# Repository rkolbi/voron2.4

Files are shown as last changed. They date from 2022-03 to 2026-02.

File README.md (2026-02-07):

##  :crystal_ball:A collection of Klipper related things.

Main files:

**[:zap:](DK-TAP-SENSORLESS-EBB36-CPAP-BEDFANS)My currently running configuration setup (Kalico, ChaoticLab Tap V2, EBB36 Can, Sensorless XY, CPAP Part Cooling, and Bedfans).**

**[:bulb:](gcode_folder_share.txt)How to network share your gcode folder.**

**[:bulb:](ADXL345-NANO.txt)Using an Arduino nano & ADXL345.**

**[:bulb:](PA_CAL-V1)Pressure Advance Macro - version 1.**

**[:bulb:](PA_CAL-V2)Pressure Advance Macro - version 2.**

**[:wrench:](printer.cfg)Full Monolithic printer.cfg.**

**[:wrench:](Euclid)Portable Euclid probe macros.**

<br><br>
:hear_no_evil::see_no_evil::speak_no_evil: If you have any suggestions for a change, addition, or correction - please feel free to submit it [here](https://github.com/rkolbi/voron2.4/discussions/new?category=ideas).

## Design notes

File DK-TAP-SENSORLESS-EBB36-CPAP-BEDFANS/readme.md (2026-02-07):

# Voron 2.4 Configuration
## with Voron TAP, Sensorless X&Y Homing, EBB36 CAN Toolhead, and CPAP Part Cooling

---

This Kalico (DangerKlipper) configuration is optimized for the Voron 2.4 3D printer, providing comprehensive automation and advanced features for exceptional print quality and user experience.

---

## Configuration Overview

### Modular File Management

This configuration uses an intelligent directory-based system for organizing configuration files:

- **ACTIVE Directory**: All `.cfg` files in this directory are automatically loaded by Klipper
- **INACTIVE Directory**: Files stored here are ignored, allowing easy testing and organization
- **Easy Management**: Edit files via Samba network shares or SSH as if they were on your desktop

**To disable a configuration file:**
- Rename the extension (e.g., `feature.cfg` → `feature.cfgno`), OR
- Move it to the INACTIVE directory

### Central Configuration (printer.cfg)

The root `printer.cfg` file serves as the central hub:
- Automatically loads all `.cfg` files from the ACTIVE directory
- Contains global variables used throughout the macro system
- Stores auto-generated parameters (input shaper, saved mesh, etc.) at the bottom

### Printer-Specific Settings

Hardware-specific configurations are organized in dedicated files like `CONFIG-V24-350-TAP-SENSORLESS.cfg`. The modular approach ensures portability and makes updates straightforward.

---

## Key Features

### Dynamic Motor Current System

This configuration implements an intelligent safety feature:
- **Low currents** during homing and maintenance (prevents damage from collisions)
- **High currents** automatically applied during printing (full performance)
- **Collision protection** reduces risk of bent rods or damaged components

### Advanced Macro Suite

- **Adaptive Bed Mesh**: Meshes only the print area for faster, smarter leveling
- **Heat Soak Management**: Configurable pre-print chamber stabilization
- **Automated Homing & Leveling**: QGL and mesh calibration with thermal protection
- **Bed Fan Control**: Automatic chamber temperature management
- **Filament Handling**: Load/unload macros with customizable settings
- **LED Effects Integration**: Dynamic status indication (requires klipper-led_effect plugin)
- **Calibration Helpers**: PA_CAL, PID tuning, ADXL measurements

---

## Configuration Highlights

### PRINT_START Macro

The PRINT_START macro automates the entire print preparation workflow:

**Key Features:**
1. **Heat Soak Cycle**: Stabilizes chamber temperature before printing (configurable duration)
2. **Intelligent Homing**: Performs QGL and homing at optimal temperatures
3. **Adaptive Mesh**: Automatically meshes only the required print area
4. **Thermal Protection**: Ensures safe probing temperatures for Voron TAP
5. **Purge Line**: Two-stage purge for flow verification and nozzle priming
6. **Flexible Control**: Heat soak can be terminated early via RESUME or WAIT_QUIT

**Slicer Integration:**

For **OrcaSlicer/PrusaSlicer**, use this Start G-code:

```gcode
PRINT_START BED_TEMP=[first_layer_bed_temperature] EXTRUDER_TEMP=[first_layer_temperature] EXTRUDER_TEMP2=[temperature] CHAMBER_TEMP=[chamber_temperature] PA=0.040 ST=0.020 SIZE={first_layer_print_min[0]}_{first_layer_print_min[1]}_{first_layer_print_max[0]}_{first_layer_print_max[1]}
```

For **SuperSlicer**, use:

```gcode
PRINT_START BED_TEMP=[first_layer_bed_temperature] EXTRUDER_TEMP=[first_layer_temperature] EXTRUDER_TEMP2=[temperature] ENCLOSURE_TEMP=[chamber_temperature] PA=0.040 ST=0.020 SIZE={first_layer_print_min[0]}_{first_layer_print_min[1]}_{first_layer_print_max[0]}_{first_layer_print_max[1]}
```

**Optional Parameters:**

The following parameters can be specified in your slicer start code, or defaults from `printer.cfg` will be used:

- `PA=0.040` - Pressure advance value
- `ST=0.020` - Pressure advance smooth time
- `SOAK=15` - Heat soak duration in minutes (reduce for PLA/PETG, increase for ABS/ASA)
- `CHAMBER_TEMP=45` - Target chamber temperature for bed fan control

---

### LC_PAUSE (Layer Change Pause) Macro

Provides intelligent layer-based pausing functionality:

**Features:**
- Pause at next layer change (no parameter needed)
- Pause at specific layer (pass layer number as parameter)
- Toggle behavior (calling LC_PAUSE again cancels the pause)
- Seamless slicer integration

**Slicer Integration:**

Add to **After Layer Change G-code** in your slicer:

```gcode
_LAYER_CHANGE LAYER={layer_num}
```

**Usage Examples:**
```gcode
LC_PAUSE           # Pause on next layer
LC_PAUSE LAYER=50  # Pause when layer 50 starts
```

---

### PRINT_END Macro

Handles post-print cleanup and safety:

**Actions Performed:**
1. **Print Clearance**: Raises toolhead 10mm to prevent nozzle contact
2. **Cooling Activation**: Part cooling fan to 100% for rapid cooldown
3. **Smart Parking**: Positions toolhead for easy inspection and access
4. **Fan Clearance**: Moves to Y20 for unobstructed airflow
5. **Motor Current Reset**: Returns to low currents for safety

**Slicer Integration:**

Add to **End G-code**:

```gcode
PRINT_END
```

---

### PA_CAL (Pressure Advance Calibration) Macro

Simplified pressure advance tuning:

**Features:**
- Line-based PA test pattern
- Automatic value incrementation
- Customizable test parameters
- Visual validation of results

**Usage:**

```gcode
PA_CAL                                    # Use defaults from printer.cfg
PA_CAL BED=110 EXTRUDER_TEMP=245          # Specify temperatures
PA_CAL PA_START=0.020 PA_STEP=0.005       # Custom PA range
```

The macro prints test lines with incrementing PA values. Inspect the lines to find where corners look best (no bulging or gaps), then update your `printer.cfg` and slicer settings.

---

## Hardware Specifications

### Current Configuration

- **Printer**: Voron 2.4 (350mm build volume)
- **Firmware**: Kalico (DangerKlipper fork)
- **Mainboard**: BTT Octopus or similar (TMC2209 drivers)
- **Toolhead**: BTT EBB36 CAN board via U2C bridge
- **Probe**: Voron TAP with thermal protection
- **Homing**: Sensorless X/Y via TMC2209 StallGuard
- **Part Cooling**: CPAP blower with WS7040 driver
- **Extruder**: BMG-style (Bondtech LGX or similar)

### Performance Settings

- **Max Velocity**: 300 mm/s
- **Max Acceleration**: 4000 mm/s²
- **Print Acceleration**: 4000 mm/s² (via globalvariables)
- **Square Corner Velocity**: 6.0 mm/s
- **Pressure Advance**: 0.040 (tune for your filament)
- **Input Shaper**: Auto-calibrated (stored in SAVE_CONFIG)

---

## Network File Sharing Setup (Optional)

Enable easy file access from your desktop via Samba network shares.

### Installation

SSH into your Raspberry Pi and run:

```bash
sudo apt-get install samba winbind -y
```

### Configuration

Edit the Samba configuration file:

```bash
sudo nano /etc/samba/smb.conf
```

Add the following to the end of the file:

```ini
[Print_Files]
   comment = Voron G-Code Files
   path = /home/pi/printer_data/gcodes
   browseable = Yes
   writeable = Yes
   only guest = no
   create mask = 0777
   directory mask = 0777
   public = yes
   read only = no
   force user = root
   force group = root

[Klipper_Configs]
   comment = Voron Klipper Configuration
   path = /home/pi/printer_data/config
   browseable = Yes
   writeable = Yes
   only guest = no
   create mask = 0777
   directory mask = 0777
   public = yes
   read only = no
   force user = root
   force group = root

[Klipper_Storage]
   comment = Voron Storage
   path = /home/pi/Storage
   browseable = Yes
   writeable = Yes
   only guest = no
   create mask = 0777
   directory mask = 0777
   public = yes
   read only = no
   force user = root
   force group = root
```

### Apply Changes

Reboot your Raspberry Pi:

```bash
sudo reboot
```

### Windows Troubleshooting

If Windows shows a red X on mapped network shares, run CMD as administrator and execute:

```cmd
net stop workstation /y
net start workstation
```

### Accessing Shares

From Windows File Explorer or macOS Finder, navigate to:
```
\\your-printer-ip\Print_Files
\\your-printer-ip\Klipper_Configs
\\your-printer-ip\Klipper_Storage
```

---

## Tuning & Calibration

### Recommended Calibration Sequence

1. **PID Tuning** (Bed & Hotend)
   ```gcode
   PID_BED_CAL
   PID_NZL_CAL
   ```

2. **Input Shaper** (after toolhead assembly)
   ```gcode
   SHAPER_CALIBRATE
   # Or use: HEATSOAKED_ADXL for thermally stable measurements
   ```

3. **Pressure Advance** (for each filament type)
   ```gcode
   PA_CAL BED=110 EXTRUDER_TEMP=245 PA_START=0.020 PA_STEP=0.005
   ```

4. **First Layer & Z Offset** (with Voron TAP)
   - Heat bed to printing temperature
   - Run `QUAD_GANTRY_LEVEL`
   - Use paper test or first layer calibration print
   - Adjust via `SET_GCODE_OFFSET Z_ADJUST=±0.xxx` then `Z_OFFSET_APPLY_PROBE`

### Material-Specific Heat Soak Times

Adjust `SOAK` parameter in your slicer for different materials:

- **PLA**: `SOAK=0` or `SOAK=5` (minimal heat soak needed)
- **PETG**: `SOAK=5` to `SOAK=10`
- **ABS/ASA**: `SOAK=15` to `SOAK=20` (default, recommended)
- **Nylon/PC**: `SOAK=20` to `SOAK=30`

---

## Additional Resources

### Documentation & References

- **This Configuration**: [GitHub Repository](https://github.com/rkolbi/voron2.4/tree/main/MY_V24-350)
- **Adaptive Mesh**: [Frix-x's Klippain](https://github.com/Frix-x/klippain/blob/main/macros/calibration/adaptive_bed_mesh.cfg)
- **LED Effects**: [klipper-led_effect Plugin](https://github.com/julianschill/klipper-led_effect)
- **Sensorless Homing**: [Clee's Guide](https://docs.vorondesign.com/community/howto/clee/sensorless_xy_homing.html)

### Klipper Resources

- **Klipper Documentation**: [Main Docs](https://www.klipper3d.org/Overview.html)
- **Configuration Reference**: [Config Reference](https://www.klipper3d.org/Config_Reference.html)
- **G-Code Commands**: [G-Code Reference](https://www.klipper3d.org/G-Codes.html)
- **TMC Drivers**: [TMC Documentation](https://www.klipper3d.org/TMC_Drivers.html)
- **Klipper GitHub**: [Main Repository](https://github.com/Klipper3d)
- **Klipper Reddit**: [r/klippers](https://www.reddit.com/r/klippers/)

### Voron Resources

- **Voron Documentation**: [Build Guides](https://docs.vorondesign.com/build/)
- **Voron GitHub**: [VoronDesign](https://github.com/VoronDesign)
- **Voron Reddit**: [r/VORONDesign](https://www.reddit.com/r/VORONDesign/)

### Hardware Links

- **Euclid Probe**: [Documentation](https://euclidprobe.github.io/)
- **Bondtech LGX Extruder**: [Product Page](https://www.bondtech.se/product/lgx-large-gears-extruder/)
- **Bondtech CHT Nozzle**: [Product Page](https://www.bondtech.se/product/bondtech-cht-coated-brass-nozzle/)
- **MandalaRoseWorks Kinematic Mounts**: [Product Page](https://mandalaroseworks.com/products/matched-height-kinematic-kit)
- **MandalaRoseWorks Ultraflat Bed**: [Product Page](https://mandalaroseworks.com/products/voron-350-ultraflat-bed)

### General 3D Printing

- **RepRap G-code Wiki**: [G-code Reference](https://reprap.org/wiki/G-code)
- **Jinja2 Templates**: [Syntax Guide](https://jinja.palletsprojects.com/en/2.10.x/templates/)

---

## Configuration Philosophy

This configuration emphasizes:

1. **Safety First**: Dynamic current control, thermal protection, collision prevention
2. **Automation**: Minimize manual steps, maximize reliability
3. **Flexibility**: Easy to modify, well-documented, modular structure
4. **Performance**: Optimized for speed without sacrificing quality
5. **User Experience**: Clear feedback, intuitive controls, comprehensive macros

---

## Support & Contributions

For issues, improvements, or questions about this configuration:
- Review the documentation above
- Check Klipper and Voron documentation
- Consult the community resources linked above
- Submit issues or pull requests to the GitHub repository

---

**Last Updated**: February 7, 2026  
**Firmware**: Kalico v2026.02.00-0-gc70d21ab

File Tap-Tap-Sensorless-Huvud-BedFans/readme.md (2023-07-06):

****Voron 2.4 Configuration with Tap, Sensorless X&Y Homing, Bed Fans, and Huvud w/U2C****  
------

This Klipper configuration is tailored for the Voron 2.4 3D printer with Tap, offering a range of features to optimize your printing experience. Here's an overview of the key enhancements:

**Macro File Management:**

The configuration simplifies file management by automatically pulling all ".cfg" files from the ACTIVE directory while excluding any files in the INACTIVE directory. You can conveniently move and edit files using Samba or other networking file-share services as if they were on your desktop. To exclude a file from Klipper, rename its extension within the ACTIVE directory (e.g., "do_stuff.cfg" to "do_stuff.cfgno"), or move it to the INACTIVE directory. Please refer to the instructions below if you require assistance setting up Samba network sharing.

**printer.cfg:**

The root directory includes a "printer.cfg" file that loads all ".cfg" files from the ACTIVE directory. It also serves as a centralized location for modifying global variables used by the included macros. Additionally, any saved parameters generated by Klipper are stored at the bottom of the "printer.cfg" file for easy access and management.

**Printer-Specific Configurations:**

To accommodate printer-specific settings, you can create a dedicated file such as "CONFIG-VORON24_350.cfg" (feel free to choose a different name if preferred). This configuration file is specific to your Voron 2.4 printer, allowing you to organize the contents further. Remember that "printer.cfg" automatically loads all ".cfg" files from the ACTIVE directory, irrespective of their names. Therefore, it's crucial to use meaningful and portable filenames to ensure ease of use and future compatibility.<br>  
<br>

### Configuration Bundle Highlights
------

#### **PRINT_START macro**:

1. Automation: The PRINT_START macro automates multiple steps before starting a print, such as heat soaking, toolhead warming, gantry homing, and leveling. 
2. Heat-soak cycle: The macro includes a heat-soak cycle that allows the printer to stabilize its temperature before starting the actual print. This cycle is crucial for ensuring that the printer operates at the desired temperature, which is essential for successful printing and proper filament adhesion.
3. Gantry homing and leveling: As the heat-soak cycle begins, the PRINT_START macro also performs gantry homing and leveling. This step prevents any undue stress on the gantry as chamber temperatures rise, ensuring that the gantry remains properly aligned.
4. Flexibility: The heat-soak cycle can be terminated early by selecting RESUME or executing the WAIT_QUIT macro. This flexibility allows users to abort the heat-soak cycle if needed, for example, when encountering unexpected issues or when wanting to start the print sooner.
5. Adaptive Mesh: The PRINT_START macro incorporates the use of Adaptive Mesh, which improves bed leveling and compensates for any imperfections in the printing surface within the print area of the object itself. This step enhances the first-layer adhesion and overall print quality by adjusting the printing parameters based on the actual surface conditions.
6. Purge line and pressure advance proof: The macro includes a purge line and a simple line-based pressure advance proof. The purge line allows users to verify key aspects of the printer's performance, such as filament flow and pressure advance, ensuring that the printer is functioning correctly before starting the actual print.

Overall, the advantages of the PRINT_START macro lie in its automation of critical steps, gantry leveling, and temperature stabilization, flexibility in terminating the heat-soak cycle, the inclusion of Adaptive Mesh for improved bed leveling, and simplified verification of key printer parameters. These advantages contribute to a streamlined and efficient workflow, enhancing print quality and user experience.

The **Start G-code** block in SuperSlicer should contain the following line:

```
PRINT_START BED_TEMP=[first_layer_bed_temperature] EXTRUDER_TEMP=[first_layer_temperature] EXTRUDER_TEMP2=[temperature] CHAMBER_TARGET=[chamber_temperature] PA=0.045 ST=0.21 SIZE={first_layer_print_min[0]}{first_layer_print_min[1]}{first_layer_print_max[0]}_{first_layer_print_max[1]}
```

The following optional parameters can be specified, or the values set in "printer.cfg" will be used:

- **EXTRUDER_WARM**: The nozzle temperature to be used when performing the heated homing and leveling, just before printing.
- **PA**: Pressure advance, e.g., `PA=0.045`
- **ST**: Pressure advance smooth-time, e.g., `ST=0.21`
- **SOAK**: Minutes to heat-soak before final G32, meshing, and printing, e.g., `SOAK=15`
- **CHAMBER_TEMP**: The desired temperature for the chamber, e.g., `CHAMBER_TEMP=50`
- **fpline**: E value for first 120mm prime line, implemented as (fpline * NZLD), e.g., `fpline=37.5`
- **spline**: E value for second 120mm prime line, implemented as (spline * NZLD), e.g., `spline=75.0`
<br>

#### **Bed-Fan macro set:**

The Bed-Fan Macro Set offers enhanced functionality for the control of bed fans according to specific temperature conditions, providing effective control of the chamber temperature during print. 
1. Adaptive Fan Speed Control: With the macro activated, the bed fan speed seamlessly adapts to the current temperature conditions, using variable speeds to control chamber temperature while reducing temperature fluctuations witnessed on the bed. If the heater bed target temperature is below the bed-fan trigger threshold, the bed fans will be disabled.
2. Chamber Temperature Monitoring: The macro actively monitors the temperature within the chamber, ensuring that the printing environment maintains an optimal temperature range. This feature helps to enhance print quality and prevent potential issues caused by temperature fluctuations.
3. When using the gcode command `M190`, which optionally sets a new target temperature for the heated bed and waits for the target temperature to be reached before proceeding, the chamber heat-up cycle is similar in that it waits for the set temperature but will proceed regardless after 15 minutes. 

<br>  

#### **LC_PAUSE (Layer Change) macro:**

1. Convenience: The LC_PAUSE macro provides a simple and user-friendly mechanism for controlling the "Pause on the next layer" functionality. This functionality allows users to pause the printing process at a specific layer and perform certain actions or make adjustments as needed.
2. Flexibility: The macro allows flexibility in how the pause functionality is applied. Users can either pause at the next layer change by not specifying a specific layer value or trigger a pause only when a specific layer number is passed as a parameter to the macro. This flexibility caters to different use cases and allows users to customize the behavior according to their requirements.
3. Dynamic behavior: The LC_PAUSE macro considers the current state of the "Pause on the next layer" flag. If LC_PAUSE has already been set, executing the macro will toggle it off, effectively canceling the pause. This dynamic behavior ensures that users have control over the pause functionality and can easily modify it during runtime without complications.
4. Integration with slicer functionality: The macro integrates with the slicer's layer change mechanism by checking the slicer's passed layer value and comparing it with the user's specified layer. This integration enhances the compatibility and interoperability between the macro and the slicer, resulting in a more seamless workflow when managing layer-based pausing in a slicer environment.

Overall, the advantages of the LC_PAUSE macro lie in its convenience, flexibility, dynamic behavior, and integration with slicer functionality, making it a helpful tool for managing layer-based pausing in a slicer environment.

The **After Layer Change G-code** block in SuperSlicer should contain the following to enable the Pause on the next Layer Change (LC_PAUSE) command:

```
_LAYER_CHANGE LAYER={layer_num}
```

<br>  

#### **PRINT_END macro:**

1. Print clearance: When completed, the PRINT_END macro raises the toolhead by 10mm to prevent the nozzle from scarring or damaging the finished print. This step helps maintain the quality and appearance of the printed object, preventing accidental contact between the nozzle and the print.
2. Cooling activation: The macro activates the part cooling fan to 100% after the print is finished. This helps cool down the hotend and reduces the chances of stringing or unwanted filament deposits that can occur when the nozzle remains hot after the print has ended.
3. Toolhead parking: The macro parks the toolhead towards the printer's top, in the front-right position. This parking position is strategically chosen to provide optimal accessibility for visual inspection of the toolhead and nozzle, making it easier to identify and clean any debris or filament residue that may have accumulated during the print.
4. Fan clearance: The macro moves the toolhead back to Y20, allowing the fans to pull air without being obstructed by the printer's doors. This step ensures proper airflow and cooling efficiency by preventing obstructions that may impede the fans' ability to circulate air effectively and cool down the printer components.
5. Safety and maintenance: The actions performed by the PRINT_END macro contribute to the safety and maintenance aspects of 3D printing. Raising the toolhead reduces the risk of accidental damage or interference with the printed object when removing it from the build plate. Activating cooling helps prevent overheating of the printer components, which can lead to premature wear or malfunction. Parking the toolhead in a suitable position allows for easy inspection and cleaning, enhancing the longevity and reliability of the printer and preparing it for the next print job.

Overall, the advantages of the PRINT_END macro lie in its print clearance, cooling activation, toolhead parking at an accessible position, and fan clearance for proper airflow. These advantages ensure a smooth and efficient end to the print job while promoting print quality, user convenience, and printer longevity.

The **End G-code** block in SuperSlicer should contain the following line:

```
PRINT_END
```

<br>  

#### **PA_CAL (Pressure Advance) macro:**

1. Simplified Pressure Advance Testing: The PA_CAL macro enables users to perform a quick, straightforward, line-based pressure advance test. It prints a line with the current pressure advance (PA) setting, moves 30mm, and then prints 20 line segments, each 5mm apart, incrementing the PA value for each line. This simplified testing process allows users to quickly assess and fine-tune their pressure advance settings more efficiently, leading to improved print quality.
2. Customizable Parameters: The macro supports optional parameters for adjusting the test conditions. Users can specify the bed temperature (BED), extruder temperature (EXTRUDER_TEMP), initial PA value (PA_START), PA increment (PA_STEP), and nozzle diameter (NZL). This customization allows users to tailor the test conditions to their specific requirements and experiment with different settings, facilitating optimization.
3. Default Values: If no parameters are specified, the macro provides default values for the optional parameters. These default values are retrieved from the printer's configuration file or other global variables, ensuring users can perform the test without specifying all the parameters. This feature makes the macro more user-friendly and accessible.
4. Test Validation: The macro provides a mechanism to validate the test results by comparing the estimated PA threshold value with the user-specified PA threshold. This validation step helps users accurately identify the optimal PA setting and ensure reliable and consistent results during the pressure advance tuning process.

Overall, the advantages of the PA_CAL macro lie in its simplified pressure advance testing, customizable parameters, default values, and test validation. These features facilitate the optimization of pressure advance settings, allowing users to achieve better print quality and performance in their 3D prints.

<br>  
<br>

:bulb: For more information on the adaptive mesh, refer to Frix-x's github [here](https://github.com/Frix-x/klippain/blob/main/macros/calibration/adaptive_bed_mesh.cfg).

:bulb: These configs utilize Julianschill's Klipper LED Effects plugin, which can be found in [this GitHub repository](https://github.com/julianschill/klipper-led_effect).

:bulb: Bed-fan macro set is based on AndrewEllis93's work, which can be found in [this GitHub repository](https://github.com/VoronDesign/VoronUsers/tree/master/printer_mods/Ellis/Bed_Fans).

:bulb: Sensorless homing is based on Clee's work. You can find more information on sensorless XY homing for Voron printers [here](https://docs.vorondesign.com/community/howto/clee/sensorless_xy_homing.html), and Klipper documentation on TMC Drivers [here](https://www.klipper3d.org/TMC_Drivers.html#sensorless-homing).

<br>  
<br>  

### **HUVUD Setup**
------

TAP probe (optical) with Huvud toolhead controller wiring diagram follows. Detailed information on CAN [here](CAN-Application.pdf).

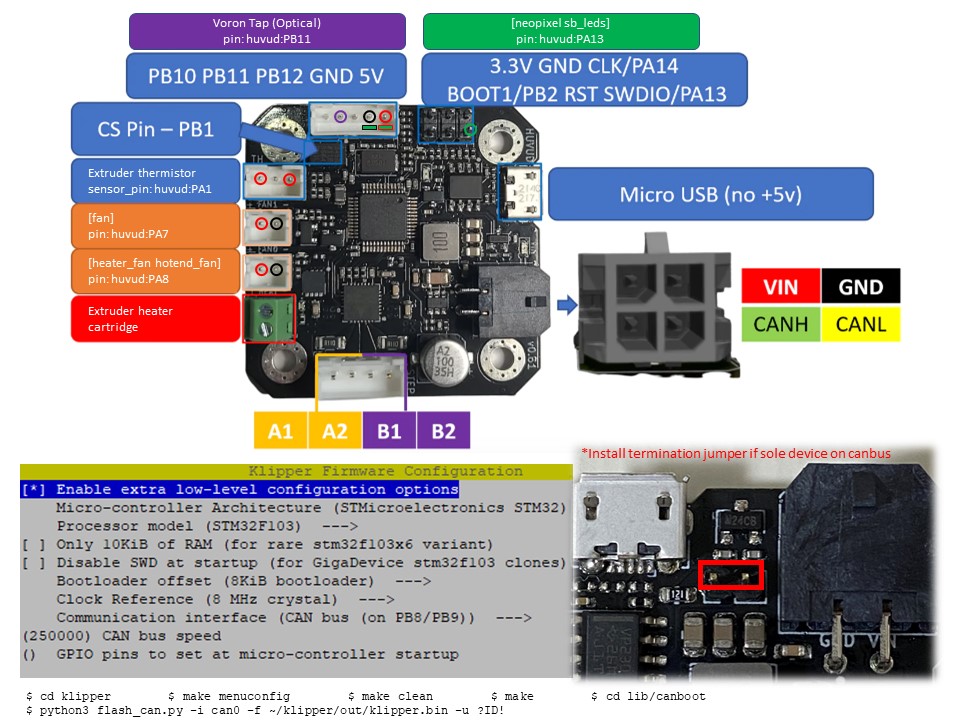
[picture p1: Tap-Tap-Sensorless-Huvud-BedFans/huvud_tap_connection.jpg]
HUVUD_TAP_Wiring

          
<br>

### **SAMBA Setup - GCODE File Network Share Setup**
------

To set up a network file share, making your gcode and Klipper config files available to all your network-attached devices - either Windows or Mac file explorers, perform the following once ssh'd into your Klipper rPi. Note that this samba configuration is 'open' and therefore accessible to any device attached to the same LAN, just as the Mainsail HTTP interface is. While it is possible to further restrict access to these Samba file shares, I feel it is a moot point given the nature of the rest of the software suite, so I will not cover that here. If this is worrisome to you, please research alternate configurations. 

 -Install file serving smb service:  
$`sudo apt-get install samba winbind -y`  

 -Configure file share.  Add the following to the end of the smb.conf file:  
$`sudo nano /etc/samba/smb.conf`  
	
```
[Print_Files]
   comment = Voron_gCode_files
   path = /home/pi/printer_data/gcodes
   browseable = Yes
   writeable = Yes
   valid users = @pi

[Klipper_Configs]
   comment = Voron_Klipper
   path = /home/pi/printer_data/config
   browseable = Yes
   writeable = Yes
   valid users = @pi

[Klipper_Storage]
   comment = Voron_Storage
   path = /home/pi/Storage
   browseable = Yes
   writeable = Yes
   valid users = @pi
```

Then create a Samba user for the pi user by running the following command.
```
sudo smbpasswd -a pi
```

Lastly, restart the Samba service to apply the changes.
```
sudo service smbd restart
```

In the event that Windows shows a red-x through the mapped share, I have found the following helpful in restoring mapped network shares:  
- Run `CMD` as administrator  
- `net stop workstation /y`  
- `net start workstation`  

<br>  

### **Links**
------

My Github (This file)                     https://github.com/rkolbi/voron2.4/tree/main/Tap-Tap-Sensorless-Huvud-BedFans  
RepRap G-code Wiki                        https://reprap.org/wiki/G-code  
Klipper Documentation (Main):             https://www.klipper3d.org/Overview.html    
Klipper Configuration Reference:          https://www.klipper3d.org/Config_Reference.html    
Klipper G-Code & Additional Commands:     https://www.klipper3d.org/G-Codes.html    
Klipper Github:                           https://github.com/Klipper3d    
Klipper Reddit:                           https://www.reddit.com/r/klippers/    
Jinja2 Syntax & Semantics:                https://jinja.palletsprojects.com/en/2.10.x/templates/    
Voron Documentation:                      https://docs.vorondesign.com/build/    
Voron Github:                             https://github.com/VoronDesign    
Voron Reddit:                             https://www.reddit.com/r/VORONDesign/    
Euclid Probe:                             https://euclidprobe.github.io/    
Bondtech LGX:                             https://www.bondtech.se/product/lgx-large-gears-extruder/    
Bontech CHT Nozzle:                       https://www.bondtech.se/product/bondtech-cht-coated-brass-nozzle/    
MandalaRoseWorks Kinematic Mounts:        https://mandalaroseworks.com/products/matched-height-kinematic-kit   
MandalaRoseWorks Ultraflat Mag Bed:       https://mandalaroseworks.com/products/voron-350-ultraflat-bed

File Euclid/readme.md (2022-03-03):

********* Instructions *********
1. Create a new Folder named "Euclid" in your /klipper_config folder
2. Copy the voron_euclid.cfg and the printer_size_xxx.cfg to the new created folder
3. Adapt the marked things inside the files to your Printer
4. You have to adapt parameters inside both files

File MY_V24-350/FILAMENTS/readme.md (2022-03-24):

This is where all your filament specific overrides go.

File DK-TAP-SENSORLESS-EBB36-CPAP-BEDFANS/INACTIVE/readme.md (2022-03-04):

Place files here to avoid being loaded by klipper.

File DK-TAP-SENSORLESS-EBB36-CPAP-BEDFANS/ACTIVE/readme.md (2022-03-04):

This directory holds all .cfg files that will be loaded into Klipper.

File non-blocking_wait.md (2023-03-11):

Going from a blocking, uninterruptable, waiting routine to an interruptible, nonblocking, routine.  
Can see this in use at:
https://github.com/rkolbi/voron2.4/tree/main/Tap-Tap-Sensorless-Huvud
In the above example, WAIT_Quit has been integrated with the normal resume function to make it more stream lined for user control.

This first snippet is my heat-waiting routine, using for loops and G4 pauses. Minutes to wait are passed on macro call. While this works well and does it's job, there is no graceful way to exit this cycle.

```
[gcode_macro _HEAT_WAIT]
description: Heating cycle waiting routine
gcode:
    {% set MINUTES = params.MINUTES|default(10)|int %}
    {% set MSG = params.MSG|default("Warming...")|string %}
    {% for i in range(0, MINUTES) %}
        M117 {MSG} {MINUTES-i} minute remaining.
        {% for s in range(0, 60) %}
            SET_LED LED=nozzle INDEX=1 RED=.5 GREEN=0 BLUE=0
            SET_LED LED=nozzle INDEX=2 RED=0 GREEN=0 BLUE=.5
            G4 P500
            SET_LED LED=nozzle INDEX=1 RED=0 GREEN=0 BLUE=.5
            SET_LED LED=nozzle INDEX=2 RED=.5 GREEN=0 BLUE=0
            G4 P500
        {% endfor %}
    {% endfor %}
```

This second snippet bundle nearly duplicates the role of the above snipper, but the wait cycle can be exited by running the macro, "WAIT_Quit". Minutes to wait are passed on calling macro, "WAIT_Start". When the cycle has completed, or forced exited, the following process macro must be directly called within the 'FINAL ACTION' block in the "WAIT_Delayed" delayed macro.

```
[gcode_macro _WAIT_Variable]
variable_count: 300
variable_duration: 2
variable_waiting: False
# Total wait minutes is (duration * count) / 60 
gcode:

[delayed_gcode WAIT_Delayed]
gcode:
    {% set count = printer["gcode_macro _WAIT_Variable"].count|int %}
    {% set duration = printer["gcode_macro _WAIT_Variable"].duration|int %}
    M117 Pre-Print Heatsoaking... {((duration * count) / 60)|round(1)} minutes left.
    SET_GCODE_VARIABLE MACRO=_WAIT_Variable VARIABLE=count VALUE={count-1}
    {% if count > 0 %} _WAIT_Loop  {% endif %}
    {% if count == 0 %} 
        # FINAL ACION
        SET_GCODE_VARIABLE MACRO=_WAIT_Variable VARIABLE=waiting VALUE=False
        M118 Reached the end, do final action
        # FINAL ACION
    {% endif %}

[gcode_macro _WAIT_Loop]
gcode:
    {% set count = printer["gcode_macro _WAIT_Variable"].count|int %}
    {% set duration = printer["gcode_macro _WAIT_Variable"].duration|int %}
    UPDATE_DELAYED_GCODE ID=WAIT_Delayed DURATION={duration}
    {% if  count % 2 == 0 %}
        SET_LED LED=nozzle INDEX=1 RED=.5 GREEN=0 BLUE=0
        SET_LED LED=nozzle INDEX=2 RED=0 GREEN=0 BLUE=.5
      {% else %}
        SET_LED LED=nozzle INDEX=1 RED=0 GREEN=0 BLUE=.5
        SET_LED LED=nozzle INDEX=2 RED=.5 GREEN=0 BLUE=0
    {% endif %}

[gcode_macro WAIT_Start]
gcode:
    {% set MINUTES = params.MINUTES|default(15)|int %}
    {% set duration = printer["gcode_macro _WAIT_Variable"].duration|int %}
    {% set count = (MINUTES * 60) / duration %}
    SET_GCODE_VARIABLE MACRO=_WAIT_Variable VARIABLE=waiting VALUE=True
    SET_GCODE_VARIABLE MACRO=_WAIT_Variable VARIABLE=count VALUE={count}
    UPDATE_DELAYED_GCODE ID=WAIT_Delayed DURATION={duration}

[gcode_macro WAIT_Quit]
gcode:
    {% if printer["gcode_macro _WAIT_Variable"].waiting %}
        M118 STOPPING LOOP, SETTING COUNT TO 0
        SET_GCODE_VARIABLE MACRO=_WAIT_Variable VARIABLE=count VALUE=0
        UPDATE_DELAYED_GCODE ID=WAIT_Delayed DURATION=1
      {% else %}
        M118 Not in waiting state, nothing to do.
    {% endif %}
```

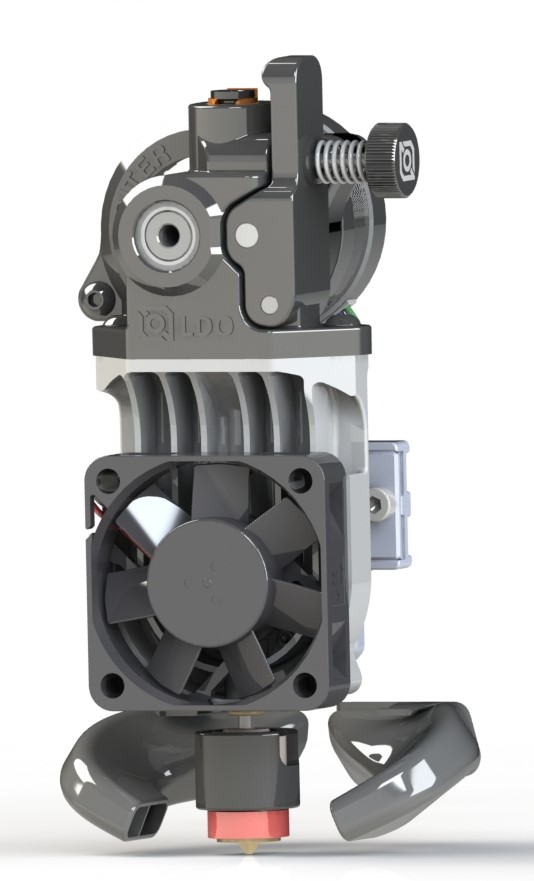
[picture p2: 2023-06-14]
CNC-Tap with Revo/buick.JPG

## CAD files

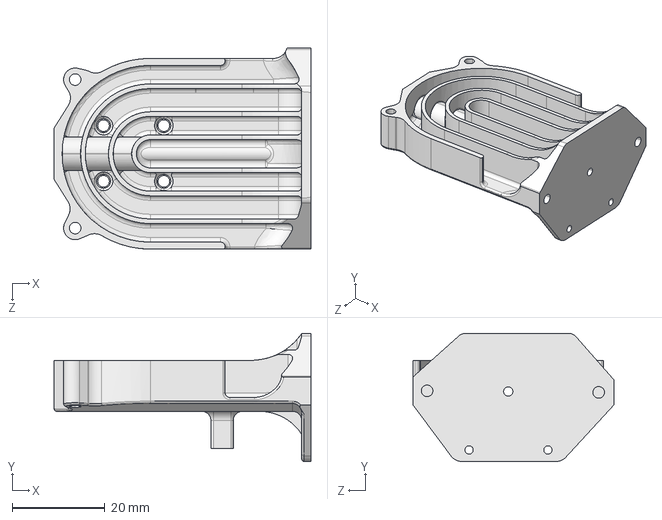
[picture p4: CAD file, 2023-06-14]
CNC-Tap with Revo/Revo-Heatsink.STEP
55.4 x 27.6 x 43.4 mm

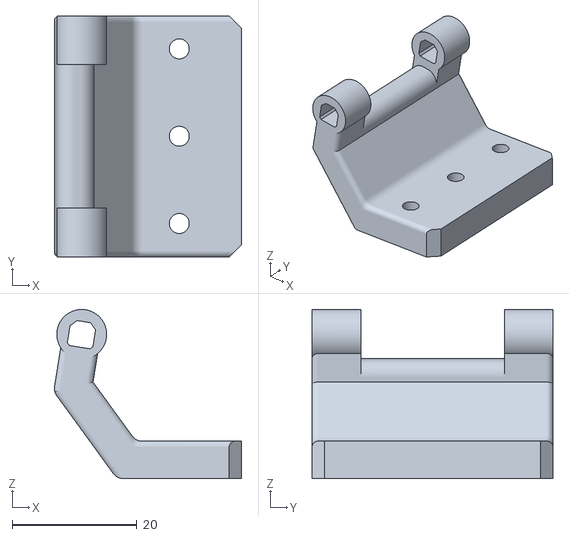
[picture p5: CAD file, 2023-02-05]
DK-TAP-SENSORLESS-EBB36-CPAP-BEDFANS/Other/STLs/c920-Top_Mount/C920_Top-Mount.stl
30.0 x 38.7 x 27.1

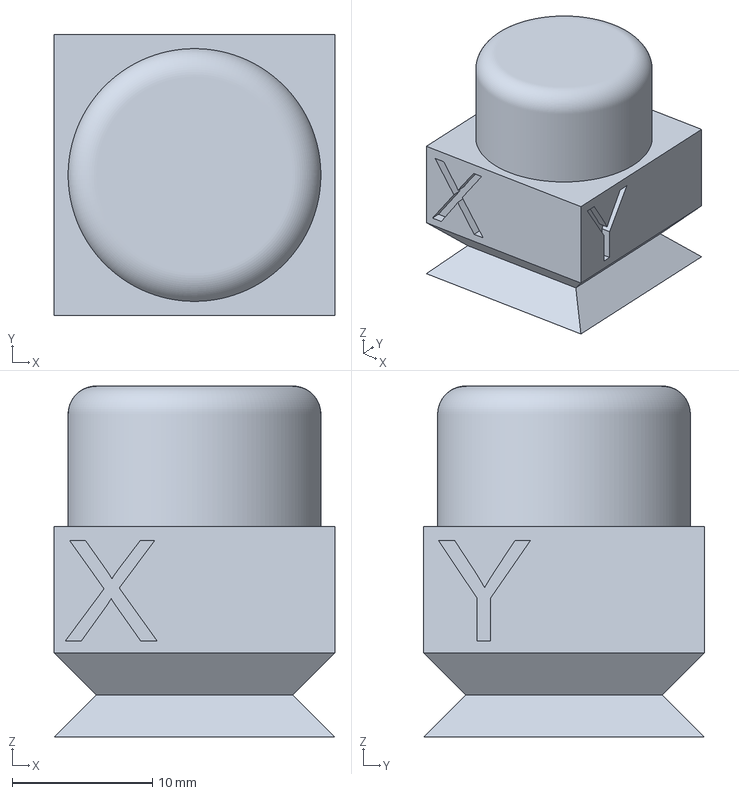
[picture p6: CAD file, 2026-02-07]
DK-TAP-SENSORLESS-EBB36-CPAP-BEDFANS/Other/STLs/Test-prints.3mf
20.0 x 20.0 x 25.0 mm

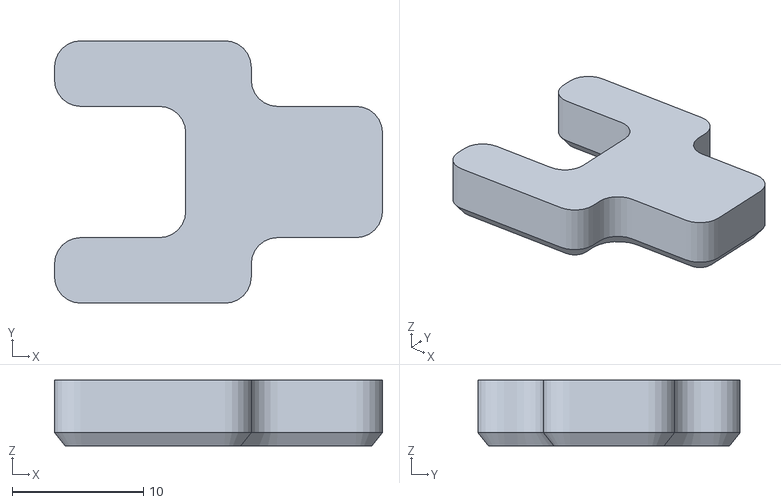
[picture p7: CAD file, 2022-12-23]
Other/Extrusion_Test.stl
25.0 x 20.0 x 5.00

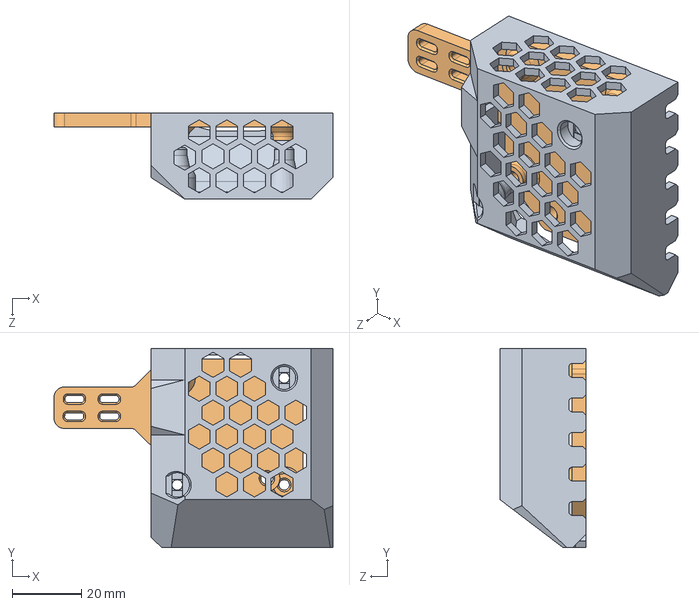
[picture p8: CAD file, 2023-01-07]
Tap-Tap-Sensorless-Huvud-BedFans/STLs/Huvud_mount_and_cover/StealthBurner_LGX_Huvud-Mount-and-Cover.STEP
80.8 x 57.8 x 25.0 mm
Cover-Huvud-to-LGX
Mount-Huvud-to-LGX

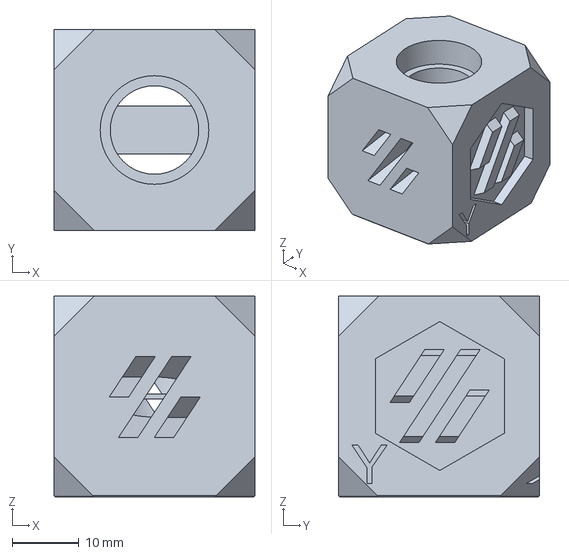
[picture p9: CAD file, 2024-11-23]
DK-TAP-SENSORLESS-EBB36-CPAP-BEDFANS/Other/STLs/Voron_Design_Cube_v7.3mf
30.0 x 30.0 x 30.0 mm

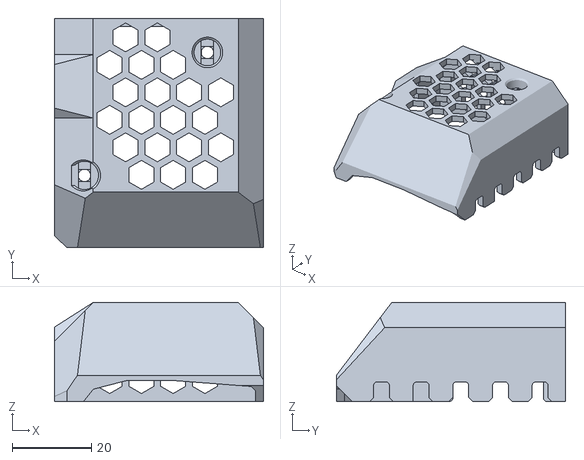
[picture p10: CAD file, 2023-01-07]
Tap-Tap-Sensorless-Huvud-BedFans/STLs/Huvud_mount_and_cover/Cover.STL
52.7 x 57.8 x 25.0

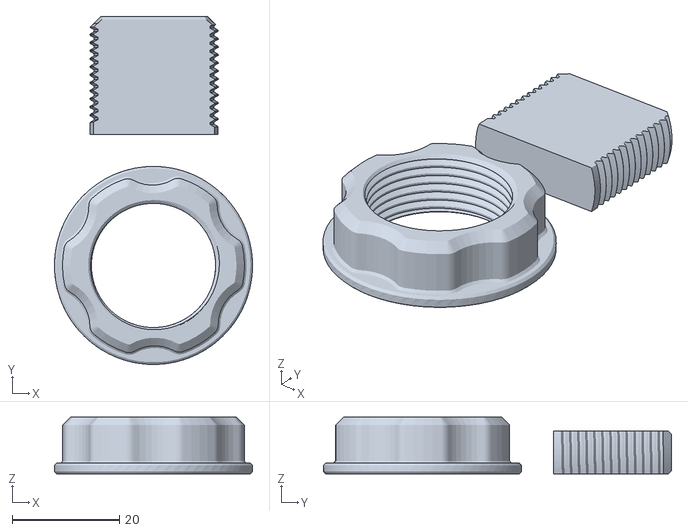
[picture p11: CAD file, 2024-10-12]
DK-TAP-SENSORLESS-EBB36-CPAP-BEDFANS/Other/STLs/Thread_Test_3_x1_Rev1.STL
37.0 x 65.0 x 10.6

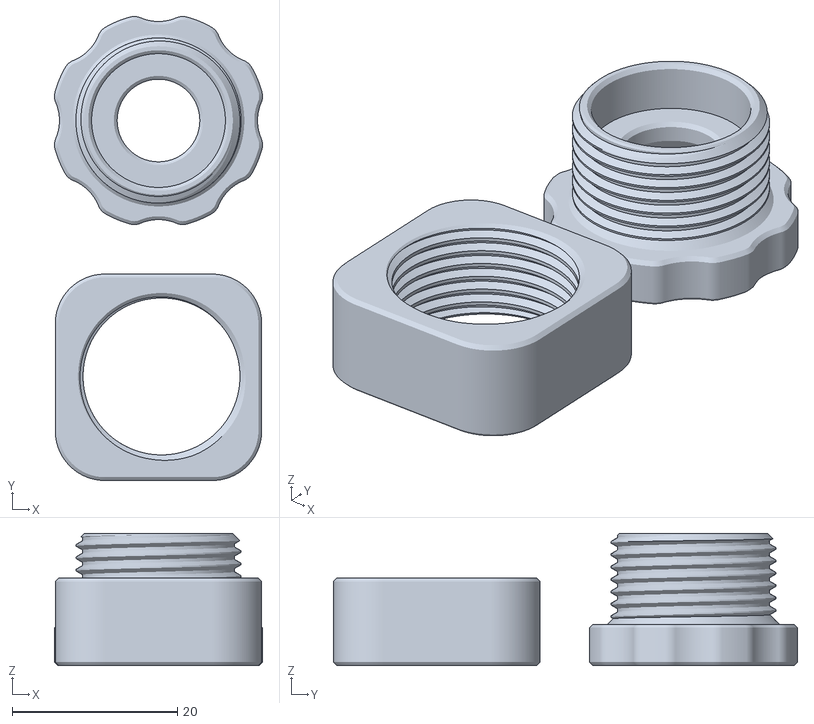
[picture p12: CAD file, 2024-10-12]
DK-TAP-SENSORLESS-EBB36-CPAP-BEDFANS/Other/STLs/Thread_Test_1_x1_Rev1.STL
25.2 x 56.2 x 16.0

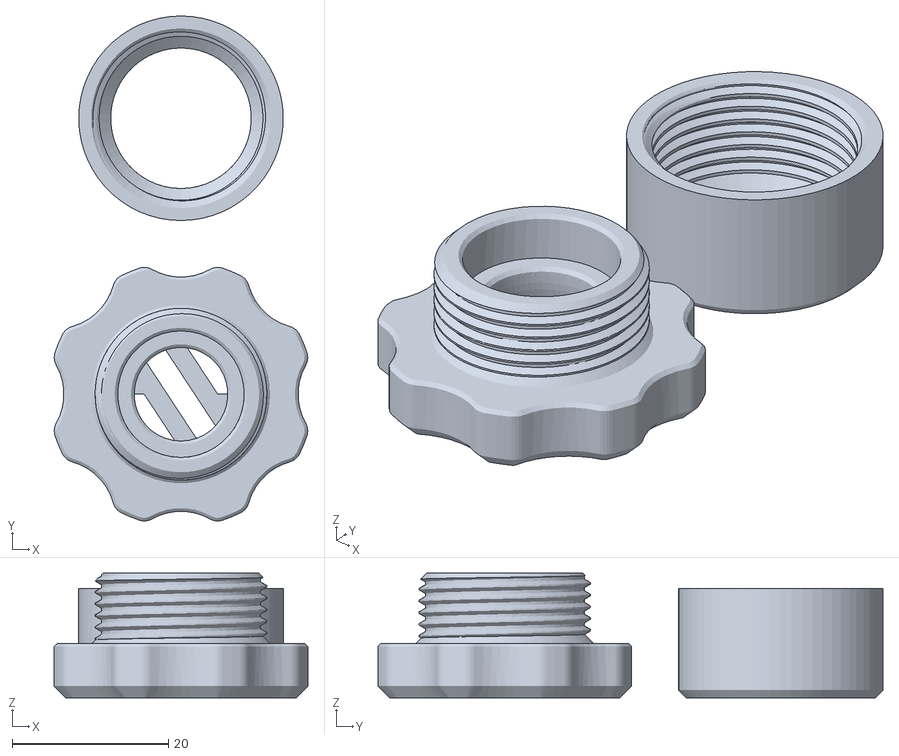
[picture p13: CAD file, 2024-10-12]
DK-TAP-SENSORLESS-EBB36-CPAP-BEDFANS/Other/STLs/Thread_Test_2_x1_Rev1.STL
32.5 x 64.7 x 16.0

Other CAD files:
DK-TAP-SENSORLESS-EBB36-CPAP-BEDFANS/Other/STLs/20x20 Test Print v3.stl
DK-TAP-SENSORLESS-EBB36-CPAP-BEDFANS/Other/STLs/Voron_Design_Cube_v7.stl

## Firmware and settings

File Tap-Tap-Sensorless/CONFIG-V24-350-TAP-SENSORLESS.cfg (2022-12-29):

#https://docs.vorondesign.com/community/howto/clee/sensorless_xy_homing.html

#.................................................................................................................
[printer]
kinematics: corexy
max_velocity: 300  
max_accel: 3000  # <<<<<<<<<<<<<<<<<<<<<<<<<<<<<<<<<<<<<<<<<<<<<<<<<<<<<<<<<<< will be adjusted by printer.cfg  <<<
max_z_velocity: 15 
max_z_accel: 350
square_corner_velocity: 5.0

[virtual_sdcard]
path: ~/printer_data/gcodes

[display_status]
# For mainsail

[pause_resume]
# For mainsail

[respond]
default_type: echo

[idle_timeout]
timeout: 1800



#.................................................................................................................
# [probe]
# !Moved to printer.cfg



#.................................................................................................................
[homing_override]
axes: xyz
set_position_z: 0.0
gcode:
    STATUS_HOMING
    SET_NOZZLE_LEDS_ON
    G90
    G0 Z10 F600
    {% set X_MID = printer.configfile.config["stepper_x"]["position_max"]|float / 2.0 %}
    {% set Y_MID = printer.configfile.config["stepper_y"]["position_max"]|float / 2.0 %}
    {% set MeshCenter = printer["gcode_macro _ADAPTIVE_MESH_VARIABLES"].mesh_center|string %}
    {% set X_MeshCenter, Y_MeshCenter = MeshCenter.split(',')|map('trim')|map('int') %}
    {% set home_all = 'X' not in params and 'Y' not in params and 'Z' not in params %}


 #   {% if printer.toolhead.homed_axes != "z" %} ; Home if not already homed
 #       G28
 #   {% endif %} 


#......Sort X
    {% if home_all or 'X' in params %}
      _HOME_X
    {% endif %}
  
#......Sort Y
    {% if home_all or 'Y' in params %}
      _HOME_Y
    {% endif %}
  
#......Sort Z
    {% if home_all or 'Z' in params %}
      G90
      #......Sort Best Center to use, printer center or mesh center
      #!!!!!! Not tested or verified !!!!!!
      {% if X_MeshCenter > 0 and Y_MeshCenter > 0 %}
          G0 X{X_MeshCenter} Y{Y_MeshCenter} F4000
        {% else %}
          G0 X{X_MID} Y{Y_MID} F4000
      {% endif %} 
      #......Finally perfrom actual G28 Z
      G28 Z
      G1 Z10
    {% endif %}
    STATUS_READY
    SET_NOZZLE_LEDS_ON


[gcode_macro _HOME_X]
gcode:
    # Always use consistent run_current on A/B steppers during sensorless homing
    {% set RUN_CURRENT_X = printer['tmc2209 stepper_x'].run_current|float %}
    {% set RUN_CURRENT_Y = printer['tmc2209 stepper_y'].run_current|float %}
    {% set HOME_CURRENT = 0.7 %}
    SET_TMC_CURRENT STEPPER=stepper_x CURRENT={HOME_CURRENT}
    SET_TMC_CURRENT STEPPER=stepper_y CURRENT={HOME_CURRENT}

    # Home
    G28 X
    # Move away
    G91
    G1 X-10 F1200
    
    # Wait just a second… (give StallGuard registers time to clear)
    G4 P1000
    # Set current during print
    SET_TMC_CURRENT STEPPER=stepper_x CURRENT={RUN_CURRENT_X}
    SET_TMC_CURRENT STEPPER=stepper_y CURRENT={RUN_CURRENT_Y}

[gcode_macro _HOME_Y]
gcode:
    # Set current for sensorless homing
    {% set RUN_CURRENT_X = printer['tmc2209 stepper_x'].run_current|float %}
    {% set RUN_CURRENT_Y = printer['tmc2209 stepper_y'].run_current|float %}
    {% set HOME_CURRENT = 0.7 %}
    SET_TMC_CURRENT STEPPER=stepper_x CURRENT={HOME_CURRENT}
    SET_TMC_CURRENT STEPPER=stepper_y CURRENT={HOME_CURRENT}

    # Home
    G28 Y
    # Move away
    G91
    G1 Y-10 F1200

    # Wait just a second… (give StallGuard registers time to clear)
    G4 P1000
    # Set current during print
    SET_TMC_CURRENT STEPPER=stepper_x CURRENT={RUN_CURRENT_X}
    SET_TMC_CURRENT STEPPER=stepper_y CURRENT={RUN_CURRENT_Y}    




#.................................................................................................................
[quad_gantry_level]
gantry_corners:
   -60,-10
   410,420
points:
   50,50
   50,300
   300,300
   300,50
speed: 100
horizontal_move_z: 10
retries: 5
retry_tolerance: 0.01
max_adjust: 10



#.................................................................................................................
[bed_mesh]
speed: 100  #    <<<<<<<<<<<<<<<<<<<<<<<<<<<<<<<<<<<<<<<<<<<<<<<<<<<<<<<<<<<<<<<<<<<<<<<<<  Bed-mesh Settings  <<<
horizontal_move_z: 3
mesh_min: 40, 40
mesh_max: 310,310
fade_start: 0.6
fade_end: 10.0
probe_count: 5,5
mesh_pps: 2,2
algorithm: bicubic



#.................................................................................................................
[stepper_x]
# B Stepper - Left, Connected to MOTOR_0, Endstop connected to DIAG_0
step_pin: PF13
dir_pin: PF12
enable_pin: !PF14
rotation_distance: 40
microsteps: 32
full_steps_per_rotation:200
#endstop_pin: !PG6
endstop_pin: tmc2209_stepper_x:virtual_endstop
position_min: 0
position_endstop: 350  #    <<<<<<<<<<<<<<<<<<<<<<<<<<<<<<<<<<<<<<<<<<<<<<<<<<<<<<<<<<<<<  X-Endstop Position  <<<
position_max: 350
homing_speed: 20   #rotation_distance of 40 / 2
homing_retract_dist: 0
homing_positive_dir: true

[tmc2209 stepper_x]
uart_pin: PC4
interpolate: false
run_current: 0.4
sense_resistor: 0.105
stealthchop_threshold: 0
diag_pin: ^PG6     # use the same pin that was previously the endstop_pin!
driver_SGTHRS: 80 # 255 is most sensitive value, 0 is least sensitive



#.................................................................................................................
[stepper_y]
# A Stepper - Right, Connected to MOTOR_1, Endstop connected to DIAG_1
step_pin: PG0
dir_pin: PG1
enable_pin: !PF15
rotation_distance: 40
microsteps: 32
full_steps_per_rotation:200
#endstop_pin: !PG9
endstop_pin: tmc2209_stepper_y:virtual_endstop
position_min: 0
position_endstop: 350  #    <<<<<<<<<<<<<<<<<<<<<<<<<<<<<<<<<<<<<<<<<<<<<<<<<<<<<<<<<<<<<  Y-Endstop Position  <<<
position_max: 354
homing_speed: 20   #rotation_distance of 40 / 2
homing_retract_dist: 0
homing_positive_dir: true

[tmc2209 stepper_y]
uart_pin: PD11
interpolate: false
run_current: 0.4
sense_resistor: 0.110
stealthchop_threshold: 0
diag_pin: ^PG9     # use the same pin that was previously the endstop_pin!
driver_SGTHRS: 80  # 255 is most sensitive value, 0 is least sensitive 


#.................................................................................................................
[stepper_z]
# Z0 Stepper - Front Left, Connected to MOTOR_2, Endstop connected to DIAG_2
step_pin: PF11
dir_pin: PG3
enable_pin: !PG5
rotation_distance: 40
gear_ratio: 80:16
microsteps: 32
endstop_pin: probe:z_virtual_endstop
position_max: 301
position_min: -3
homing_speed: 10
second_homing_speed: 5
homing_retract_dist: 5

[tmc2209 stepper_z]
uart_pin: PC6
interpolate: false
run_current: 0.3
sense_resistor: 0.110
stealthchop_threshold: 0


[stepper_z1]
# Z1 Stepper - Rear Left, Connected to MOTOR_3
step_pin: PG4
dir_pin: !PC1
enable_pin: !PA0
rotation_distance: 40
gear_ratio: 80:16
microsteps: 32

[tmc2209 stepper_z1]
uart_pin: PC7
interpolate: false
run_current: 0.3
sense_resistor: 0.110
stealthchop_threshold: 0


[stepper_z2]
# Z2 Stepper - Rear Right, Connected to MOTOR_4
step_pin: PF9
dir_pin: PF10
enable_pin: !PG2
rotation_distance: 40
gear_ratio: 80:16
microsteps: 32

[tmc2209 stepper_z2]
uart_pin: PF2
interpolate: false
run_current: 0.3
sense_resistor: 0.110
stealthchop_threshold: 0


[stepper_z3]
# Z3 Stepper - Front Right, Connected to MOTOR_5
step_pin: PC13
dir_pin: !PF0
enable_pin: !PF1
rotation_distance: 40
gear_ratio: 80:16
microsteps: 32

[tmc2209 stepper_z3]
uart_pin: PE4
interpolate: false
run_current: 0.3
sense_resistor: 0.110
stealthchop_threshold: 0

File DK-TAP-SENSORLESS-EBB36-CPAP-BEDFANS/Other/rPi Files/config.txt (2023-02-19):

# Set core / cpu frequency 
arm_freq=1200
core_freq=500
core_freq_min=500

# Automatically load overlays for detected DSI displays
display_auto_detect=1

# Enable DRM VC4 V3D driver
dtoverlay=vc4-kms-v3d
max_framebuffers=2

# Run in 64-bit mode
arm_64bit=1

# Disable compensation for displays with overscan
disable_overscan=1

[cm4]
# Enable host mode on the 2711 built-in XHCI USB controller.
# This line should be removed if the legacy DWC2 controller is required
# (e.g. for USB device mode) or if USB support is not required.
otg_mode=1

[pi4]
# Run as fast as firmware / board allows
arm_boost=1

[all]
dtoverlay=disable-bt
enable_uart=0

# Following for WaveShare CanHat Only
#dtparam=spi=on
#dtparam=spi_dma4
#dtoverlay=mcp2515-can0,oscillator=12000000,interrupt=25,spimaxfrequency=10000000
#dtoverlay=spi0-hw-cs

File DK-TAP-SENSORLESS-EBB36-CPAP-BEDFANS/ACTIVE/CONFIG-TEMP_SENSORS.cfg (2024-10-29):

#.................................................................................................................
# Other temperature sensors

[temperature_sensor Mainboard_MCU]
sensor_type: temperature_mcu
min_temp: 0
max_temp: 100


[temperature_sensor RaspberryPi]
sensor_type: temperature_host
min_temp: 10
max_temp: 100


#[temperature_sensor Extruder_MCU]
#sensor_mcu: ebb36
#sensor_type: temperature_mcu
#min_temp: 10
#max_temp: 100


[temperature_sensor Chamber]
sensor_type: ATC Semitec 104NT-4-R025H42G
sensor_pin: PF4
min_temp: 0
max_temp: 300

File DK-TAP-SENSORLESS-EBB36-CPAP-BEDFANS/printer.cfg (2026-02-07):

#------------------------------------------- MAIN MCU ---------------------------------------------
[mcu]
serial: /dev/serial/by-id/usb-Klipper_stm32f446xx_160022001950534146373920-if00
restart_method: command

[mcu ebb36]
canbus_uuid: c5ef2c34b2c8


#------------------------------------------- LOAD ALL ACTIVE CFGs ---------------------------------
# Loads all configuration files from the [ACTIVE] directory.
[include ACTIVE/*.cfg]


#------------------------------------------- ARC SUPPORT ------------------------------------------
[gcode_arcs]
resolution: 0.5
# An arc will be split into segments. Each segment's length will equal the resolution in the mm set above.
# Lower values will produce a finer arc, but also more work for your machine. Arcs smaller than the
# configured value will become straight lines. The default is 1mm.

#------------------------------------------- EXTRUDER ---------------------------------------------
[extruder]
nozzle_diameter: 0.4                   # Nozzle Diameter
pressure_advance: 0.040                # The Default Pressure Advance
pressure_advance_smooth_time: 0.020    # Pressure Advance Smooth-Time

[firmware_retraction]
retract_length: 0.80                   # The length of filament (in mm) to retract (G10) / unretract (G11)
retract_speed: 30                      # The speed of retraction, in mm/s. The default is 20 mm/s
unretract_extra_length: 0              # The length (in mm) of *additional* filament to add when unretracting
unretract_speed: 30                    # The speed of unretraction, in mm/s. The default is 10 mm/s

[gcode_macro globalvariables]
#------------------------------------------- PRINT ACCEL LIMITS ----------------------------------- 
variable_LimitAccel: 4000              # ACCEL velocity limit
variable_LimitDecel: 1700              # DECEL velocity limit

#------------------------------------------- NON-PRINT ACCEL LIMITS -------------------------------
variable_NPLimitAccel: 2000            # Accel velocity limit
variable_NPLimitDecel: 1550            # Decel velocity limit

#------------------------------------------- DEFAULT TEMPERATURES ---------------------------------
variable_defaultTempNozzle: 242        # NOZZLE EXTRUDING temperature if none is specified
variable_defaultWarmNozzle: 160        # NOZZLE WARMING temperature if none is specified. This is also used as the
                                       # maximum temperature to allow TAP probing
variable_defaultTempBed: 110           # BED temperature if none is specified
variable_bedfanChamberTemp: 45         # The target temperature for the chamber bed fans to turn on
                                  
#------------------------------------------- HEATSOAK & COOLING -----------------------------------
variable_PrePrintSoakMinutes: 15       # Minutes to heat-soak prior to printing
variable_HotmeshSoakMinutes: 15        # Minutes to heat-soak prior to running mesh
variable_QGLbeforeSoakMesh: True       # (True/False) Perfrom QGL before applying heat soak for HOTMESH 
variable_PostPrintCool: 2              # Post-Print cooling to prevent nozzle string, minutes of cooling
                                       # or until nozzle temp < 'defaultWarmNozzle' setting
variable_PostPrintParkCool: 1          # Once parked, minutes of cooling or until nozzle temp < 80C

#------------------------------------------- OTHER RETRACTIONS ------------------------------------
variable_purgeRetract: 0.3             # After completing the purgeline, how much retraction to perform
variable_EndRetract: 5.0               # After the print has been completed, how much retraction to perform

#------------------------------------------- BED FANS CONTROL -------------------------------------
variable_bedFanMAX: 0.60               # The MAX speed to use for bedfans
variable_bedFanMIN: 0.20               # The MIN speed to use for bedfans
variable_BedFanNormal: 0.21            # The speed just below the temp that maintains the chamber temperature
variable_BedFanTripON: 90              # The bed temp where threshold that will cause the bedfans to be enabled

#------------------------------------------- FILAMENT SETTINGS ------------------------------------
variable_Filament_Load: 150            # Distance (MM) of filament to load during filament handling, max 300
variable_Filament_UNLoad: 150          # Distance (MM) of filament to unload during filament handling, max 300
variable_FpLine: 37.5                  # Get E value for first 120mm prime line, implemented as (fpline * NZLD)
variable_SpLine: 75.0                  # Get E value for second 120mm prime line, implemented as (spline * NZLD)

#------------------------------------------- PRINTING MOTOR CURRENTS ------------------------------
variable_PrintCurrentXY: 1.2           # Steppermotor current to be used while printing
variable_PrintCurrentZ: 0.8            # Steppermotor current to be used while printing

#------------------------------------------- PARKING ----------------------------------------------
variable_ParkHeightPercentage: 0.50    # The percentage of Z height to park the nozzle, expressed as 0.2 to 1.0
                                       # If the printed object is taller than the expressed Z-axis percent height,
                                       # the toolhead will then park 10mm above the object.    

#------------------------------------------- ADXL HeatSoak ----------------------------------------
variable_ADXLsoakMinutes: 30           # Minutes to heat-soak prior to ADXL measurements
gcode:
    M117 Happy Printing!



#-#-#-#-#-#-#-#-#-#-#-#-#-#-#-#-#-#-#-#-#-#-#-#-#-#-#-#-#-#-#-#-#-#-#-#-#-#-#-#-#-#-#-#-#-#-#-#-#-#-#-#-#-#-#-#-#

#*# <---------------------- SAVE_CONFIG ---------------------->
#*# DO NOT EDIT THIS BLOCK OR BELOW. The contents are auto-generated.
#*#
#*# [input_shaper]
#*# shaper_type_x = mzv
#*# shaper_freq_x = 52.2
#*# shaper_type_y = 3hump_ei
#*# shaper_freq_y = 66.6

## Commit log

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2022-02-21 Added safety for applyig Z-Offset
    Added safety for applying Z-Offset from calibration findings obtained during hotmesh. If calculated difference is > 1mm then it will not be applied. This will protect cases for when a hotmesh has not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
    [TESTING-printer.cfg]
2022-02-26 Create TESTING-z_cal.cfg
    ZP_CAL is how you adjust your Z offset from bed surface when using this macro system. The bigger the number - the closer the nozzle is to the bed.
    [TESTING-z_cal.cfg]
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2022-02-28 Add files via upload
    Retrofit solution für Voron 2.4 250, can easily be adapted to other sizes
    [euclid-2.cfg]
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2022-03-01 Update TESTING-printer.cfg
    Give the ability to not QGL before heat-soak for hotmesh and print.
    [TESTING-printer.cfg]
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2022-03-02 Change Tolerances to 0.020 and probing speed from 5 to 3
    [voron_retro_euclid.cfg]
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2022-03-02 Small corrections
    [voron_retro_euclid.cfg]
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2022-03-03 Fix Bed_Mesh
    [voron_retro_euclid.cfg]
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2022-03-04 Update voron_euclid.cfg
    Fixed variable error, in some instances zprobesamples was used instead of zprobespeed
    [voron_euclid.cfg]
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2022-03-07 Fix spelling
    [CONFIG-ENCLOSURE_CONTROL.cfg, CONFIG-NO_ENCLOSURE_CONTROL.cfg, MACRO-PRINT_HANDLING.cfg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]
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2022-03-12 Euclid Gantry Mount Changes
    Changed configs to work for Euclid dock mounted on the GANTRY, and also removed any ref to Z-Endstop. Previous file for Euclid probe mounted on bed are called out by having (BM) in their name, where 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
    [CONFIG-VORON24_350_EUCLID(BM).cfg, CONFIG-VORON24_350_EUCLID(GM).cfg, MACRO-EUCLID(BM)_with_Z-COMP.cfg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]
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2022-03-13 Update MACRO-EUCLID(BM)_with_Z-COMP.cfg
    Added thanks to Daniel0815 for testing & assistance on Z compensation.
    [MACRO-EUCLID(BM)_with_Z-COMP.cfg]
2022-03-16 Added SOAK parameter
    Added the ability to pass SOAK=XX to hotmesh and print start routines. If not specified, the value set in printer.cfg will be used.
    [CONFIG-BED.cfg, MACRO-HOTMESH.cfg, MACRO-PRINT_HANDLING.cfg]
2022-03-16 Minor improvements
    Corrected redundant probe stowing, added ability to change park height percentage in printer.cfg and via cli.
    [CONFIG-BED.cfg, MACRO-EUCLID(GM).cfg, MACRO-PARKING.cfg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]
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2022-03-18 Added [endstop_phase]
    With Euclid we can employ Klipper's stepper phase adjusted endstop system. See the following link for usage.
    [MACRO-EUCLID(GM).cfg, printer.cfg]
2022-03-20 G3201 Improvement
    Added probe height checking to G3201 function. This utilizes the probe function to get the best current height and will adjust Z height to match the offset as defined in "[probe] z_offset".
    [MACRO-EUCLID(GM).cfg, MACRO-PRERUN.cfg, printer.cfg]
2022-03-22 QoL improvements wrt settings
    All commonly used adjustments are now in printer.cfg
    This update includes minor cleanups, but mostly the moving of settings like nozzle diameter, pressure advance, and retractions to the main printer.cfg - which only contains settings. Before this, ext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
    [CONFIG-EXTRUDER.cfg, MACRO-PRERUN.cfg, MACRO-PRINT_HANDLING.cfg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]
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2022-03-26 Moved filament file MAX-ACCEL setting
    Removed [printer] section from filament file. This part was for changing MAX Accel, now that is a variable in 'globalvariables', located several lines down in the filament file, and is set before pur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
    [ABS04.cfg, PETG04.cfg]
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2022-03-30 TESTING - TESTING - TESTING - TESTING - TESTING
    TESTING - TESTING - TESTING - TESTING - TESTING
    [MACRO-EUCLID(GM)-TESTING.cfg]
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2022-04-01 Changed default Non-Print
    When changing speeds or accels, be advised that this can throw off your z-offset as timing will differ slightly. Whenever changing such, be watchful on first layer.
    [printer.cfg]
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2022-04-09 Minor update
    Corrected small error in MACRO-EASY_ADXL.cfg, was using incorrect variable (not defined) for bed temp.
    [CONFIG-BED.cfg, MACRO-EASY_ADXL.cfg, printer.cfg]
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2022-04-26 Update MACRO-EUCLID(GM).cfg
    Thanks to Zaffor for finding variable label error in zprobespeed!
    [MACRO-EUCLID(GM).cfg]
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2022-05-02 Updated [homing_override]
    Updated [homing_override] z-homing routine to adjust toolhead position with regard to [probe] x/y offsets prior to performing G28 Z.
    [MACRO-EUCLID(GM).cfg]
2022-05-05 Added Non-blocking heat-soak
    Added non-blocking / interruptible pre-print heatsoak. This gives the ability to cancel the heatsoak waiting period and starting printing immediately by executing the WAIT_QUIT macro.
    [ABS04.cfg, MACRO-BREAKABLE_WAIT.cfg, MACRO-NONBLOCKING_WAIT.cfg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]
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2022-05-18 Minor, spelling corrections
    [MACRO-ADAPTIVEMESH.cfg, MACRO-EUCLID_GANTRY-MOUNT.cfg, MACRO-TUNE-HOTMESH.cfg]
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2022-08-01 Update MACRO-ADAPTIVEMESH.cfg
    xMin, xMax, etc are defined in an unreachable if statement if nominal bed mesh is required, which gives an undefined variable error on lines 185 and 186 - values from the config should be used instead.
    [MACRO-ADAPTIVEMESH.cfg]
2022-08-12 Added filament z comp
    Added ability to change z offset for the loaded filament by passing FILAMENT_ZCOMP=0.XX via slicer start gcode.
    [CONFIG-BED.cfg, CONFIG-EXTRUDER.cfg, MACRO-PRINT_HANDLING.cfg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]
2022-08-14 Update MACRO-PRINT_HANDLING.cfg
    Moved filazcomp from PRINT_START2 to FILAMENT_READY with use of variable Z_POS = printer.toolhead.position.z for calcs.
    [MACRO-PRINT_HANDLING.cfg]
2022-10-02 Line 42 & Adaptive mesh issue
    Since utilizing adaptive mesh, line 42 needs to have the size parameter pass. I am currently on travel but will test the following solutions on return.
    PRINT_START BED_TEMP={BED} EXTRUDER_TEMP={EXTRUDER} SIZE="100_100_220_250"
    -or-
    SIZE="{(X_MID-40)}_{(Y_MID-65)}_{(X_MID+40)}_{(Y_MID-35)+(5*20)}"
    PRINT_START BED_TEMP={BED} EXTRUDER_TEMP={EXTRUDER} SIZE={SIZE}
    [MACRO-TUNE-PA_CAL.cfg]
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2022-12-14 Update MACRO-ADAPTIVEMESH.cfg
    Allows the same operations as previous, but also allow use of [exclude_object] if slicer is not setup to pass object size. However, passing object size is still better as this will be the true size o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
    See https://github.com/Frix-x/klipper-voron-V2/blob/main/doc/features/adaptive_bed_mesh.md for more information.
    [MACRO-ADAPTIVEMESH.cfg]
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2022-12-28 Update CONFIG-VORON24_350.cfg
    Increased Z min position from -1 to -3 to facilitate gantry drift, for when machine is powered off for extended time.
    [CONFIG-VORON24_350.cfg]
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2022-12-29 Corrected gantry corners for tap
    [CONFIG-V24-350-TAP-SENSORLESS.cfg, CONFIG-VORON24_350.cfg]
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2023-04-10 Implement status_error
    Implemented status_error LED gcode, to be used with on_error_gcode in virtual_sdcard
    [CONFIG-V24-350-TAP-SENSORLESS.cfg, MACRO-KLIPPER_LED_EFFECTS.cfg]
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2023-05-09 Reverting filament change process
    [MACRO-FILAMENT_HANDLING.cfg, MACRO-HELPER_COMMANDS.cfg, MACRO-PRINT_HANDLING.cfg]
2023-05-10 Fixed spelling error
    [MACRO-HOMING_LEVELING.cfg]
2023-05-11 Updated M600 function
    Updated M600 function, based of JamesH's solution.
    Do note to use SWAP_RESUME to safely resume print.
    [MACRO-HELPER_COMMANDS.cfg]
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2023-05-26 Update MACRO-PRINT_HANDLING.cfg
    -Added Pause on Next Layer Change Ability
    -Corrected LED settings on resume print
    [MACRO-PRINT_HANDLING.cfg]
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2023-06-23 Fan control
    Prevent bedfans from shifting into slow speed while printing.
    [MACRO-BED_FANS.cfg, MACRO-PRINT_HANDLING.cfg]
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2023-06-25 Update MACRO-BED_FANS.cfg
    The Fan Heater Control is designed to regulate the fan speed of a the bed-heating to efficiently heat up the chamber while preventing overshooting. It incorporates proportional control with stall protection to provide accurate temperature control.
    [MACRO-BED_FANS.cfg]
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2023-07-02 Bedfan error corrections
    [MACRO-BED_FANS.cfg, MACRO-PRINT_HANDLING.cfg, MACRO-WAITING_ROUTINES.cfg]
2023-07-02 error fix
    [MACRO-BED_FANS.cfg, MACRO-WAITING_ROUTINES.cfg]
2023-07-02 bedfan fixes
    [MACRO-BED_FANS.cfg, MACRO-PRINT_HANDLING.cfg, MACRO-WAITING_ROUTINES.cfg]
2023-07-02 Update MACRO-PRINT_HANDLING.cfg
    Corrected syntax error in warming nozzle.
    [MACRO-PRINT_HANDLING.cfg]
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2024-11-02 Updated/Fixed MACRO-BED_FANS
    Repaired fan speed logic where the lowest running fan speed is now 'bedfanlowestspin'.
    [MACRO-BED_FANS.cfg]
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2025-07-16 Update MACRO-BED_FANS.cfg
    After moving the printer to a warmer environment, I noticed that the chamber temperature tends to run away a bit since the fans continue running at minimum speed—even when the chamber temperature far exceeds the target. To help mitigate this, I’ve added a setting that defines how many degrees (in °C) above the target temperature the chamber can go before the fans shut off for safety.
    While this revision doesn't prevent the chamber from heating further, it does slow the rate of temperature increase considerably.
    The only other solution would be to introduce cooler external air into the chamber to counter this, but for my current needs, I don’t see that a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
    [MACRO-BED_FANS.cfg]
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2026-02-07 Improve bed-fan safety, accel, retract & docs
    Multiple Voron 2.4 configuration updates and documentation refresh:
    - ACTIVE/CONFIG-V24-350-TAP-SENSORLESS.cfg: increase max_accel to 4000 mm/s², raise square_corner_velocity to 6.0, and adjust stepper sense_resistor from 0.105 -> 0.110.
    - ACTIVE/MACRO-BED_FANS.cfg: add bed chamber safety variable (bedfanchambersafety) and rewrite the delayed_gcode bedfanloop. New logic centralizes variables, adds a safety cutoff that pauses fans if chamber temperature exceeds target + safety offset, improves proportional control, anti-oscillation, outboard fan handling, and schedules the loop reliably.
    - Other/STLs/Test-prints.3mf: binary/test prints updated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
    [CONFIG-V24-350-TAP-SENSORLESS.cfg, MACRO-BED_FANS.cfg, Test-prints.3mf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]
